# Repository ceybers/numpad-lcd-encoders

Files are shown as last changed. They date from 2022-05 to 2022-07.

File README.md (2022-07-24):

# numpad-lcd-encoders

## 📻 Project Description

A wired numberpad in 4×4 layout, with 3× rotary encoders, and a 128×64 LCD display.

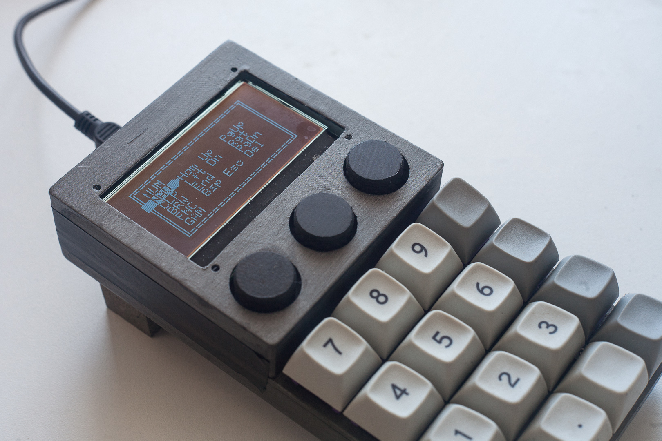
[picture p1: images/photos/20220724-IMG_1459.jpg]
Photo of first prototype


## 🧰 Features

- 4×4 programmable keys
- 3× rotary encoders (rotate and click)
- 128×64 3.25" LCD display
- [KMK firmware](https://github.com/KMKfw/kmk_firmware)
- Micro-USB connector 

## 📐 Changes

- Changed from 5×3 layout to 4×3 layout
- Changed screen to `12864-WB-33V`
- Changed from standoff plates to enclosed shell
- Increased switch plate thickness from 1.5mm to 3.0mm
- Removed holes in bottom plate for trimpot/reset button

## ⏳ Issues

> ⚠ Not suitable for actual use. Use at your own risk!

- Spacing for switches is tight, to the point that the plate will warp and might snap (printer tolerances may vary)
- Top shell around screen can't be secured to rest of case
- Shell too tall for even 20mm rotary encoders

See: [Lessons Learnt Part 1](lessons1.md), [Part 2](lessons2.md), and [Part 3](lessons3.md)

## 🛒 Bill of Materials (BoM)

> ⚠ Bill still hasn't been updated

| Item | Size | Qty | Store |
| ---- | ---- | --- | ----- |
| Raspberry Pi Pico | N/A | 1 | [Raspberry official](https://www.raspberrypi.com/products/raspberry-pi-pico/)
| EC11 Rotary Encoder | ø6×20mm shaft | 3 | [Robotics.org.za](https://www.robotics.org.za/EC11-VER-20)
| LCD Display 128×64 | 93×70mm OD | 1 | [Robotics.org.za](https://www.robotics.org.za/12864-WH-33V)
| ~~LCD I2C Interface Module~~<sup>1</sup> | N/A | ~~1~~ | [Robotics.org.za](https://www.robotics.org.za/6970622931577)
| Switches | MX | 15 |
| Diodes, 1N4148 | N/A | 18 |
| Standoffs | M3×10mm | 6 | [Robotics.org.za](https://www.robotics.org.za/M3-NYLON-KIT)
| Standoffs | M3×8mm | 4 |
| Standoffs | M3×6mm | 4 |
| Screws | M3×6mm | 6 |
| Screws | M2×?mm | 4 |
| Nuts | M3 | 6 |
| Nuts | M2 | 4 |
| 3D printed shell | N/A | 3 pcs |
| Encoder knobs | ø18×16mm | 3 pcs |
| JST-SH male breakout (optional) | JST-SH 6 pin | 4 pcs | [Robotics.org.za](https://www.robotics.org.za/4772), [Pololu](https://www.pololu.com/product/4772)
| JST-SH female connectors (optional) | JST-SH 6 pin | 4 pcs | [Robotics.org.za](https://www.robotics.org.za/JST-XH-6P-KIT) |

Notes:
1. I2C interface not required for the ST7565 controller version of the LCD board as it already utilises SPI.

---

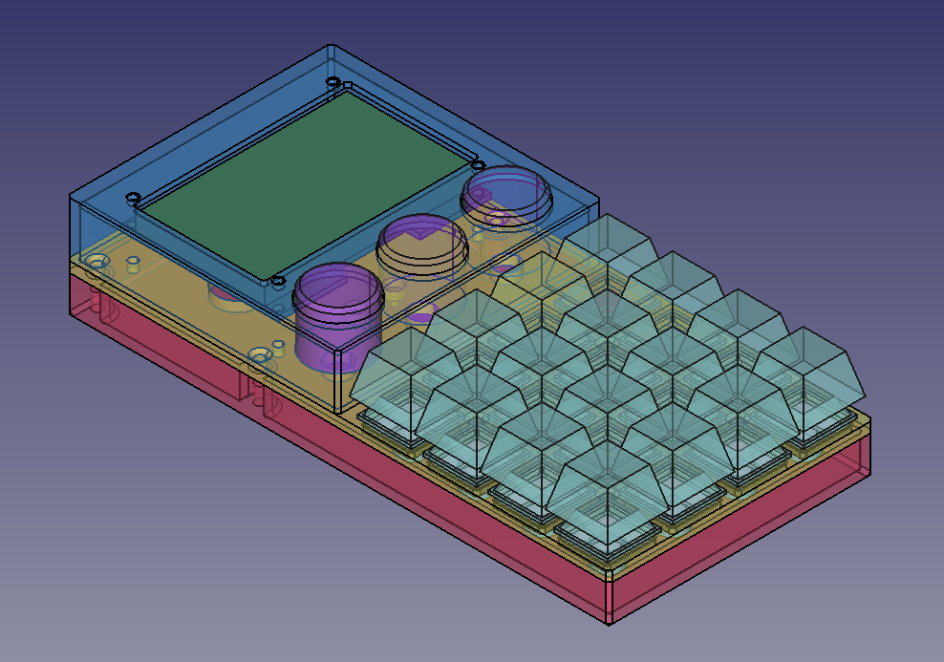
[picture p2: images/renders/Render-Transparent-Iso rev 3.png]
Render of the numberpad pad (transparent)

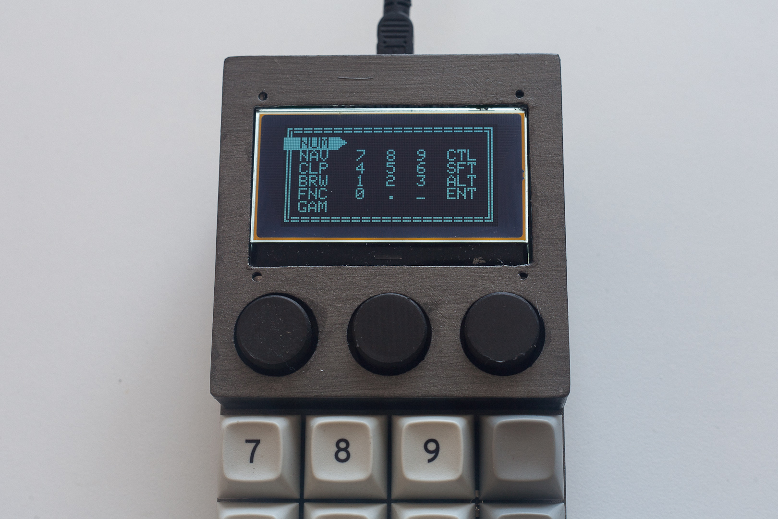
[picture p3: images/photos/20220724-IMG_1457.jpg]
Photo showing a close-up of the screen

## 🔗 References

- [KMK firmware](https://github.com/KMKfw/kmk_firmware)
- [Raspberry Pi Pico Datasheet](https://datasheets.raspberrypi.com/pico/pico-datasheet.pdf)
- [CircuitPython UF2 for Pico](https://circuitpython.org/board/raspberry_pi_pico/)

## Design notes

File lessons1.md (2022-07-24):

# Lessons Learnt Part 1

## Prototype 1
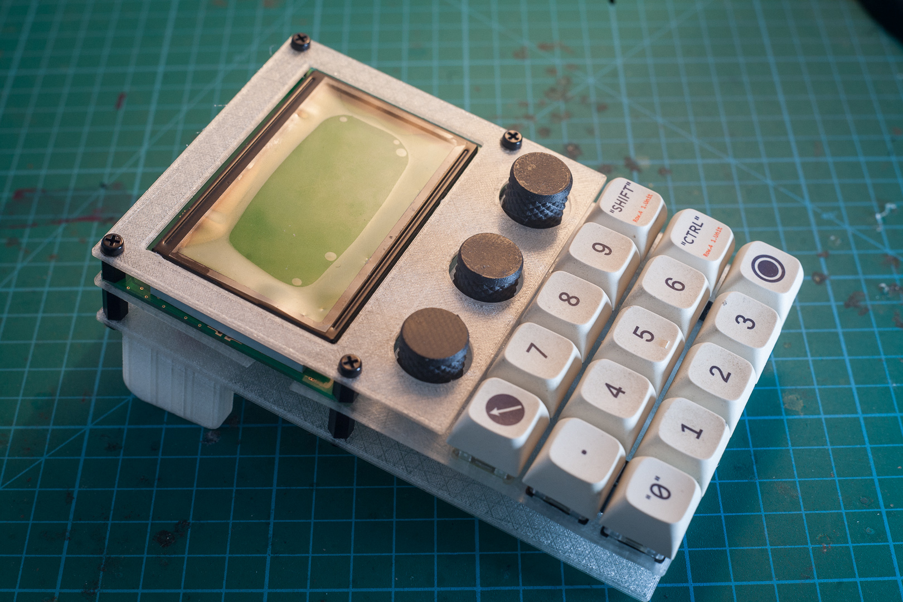
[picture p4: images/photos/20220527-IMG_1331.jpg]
High angle

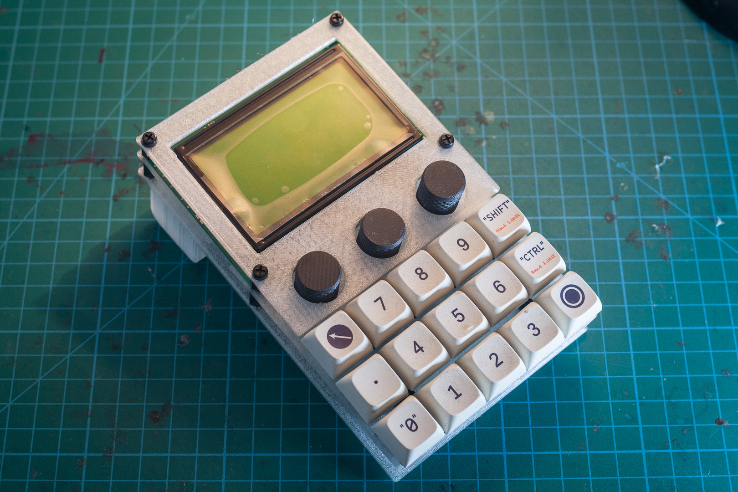
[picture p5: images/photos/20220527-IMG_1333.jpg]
Low angle

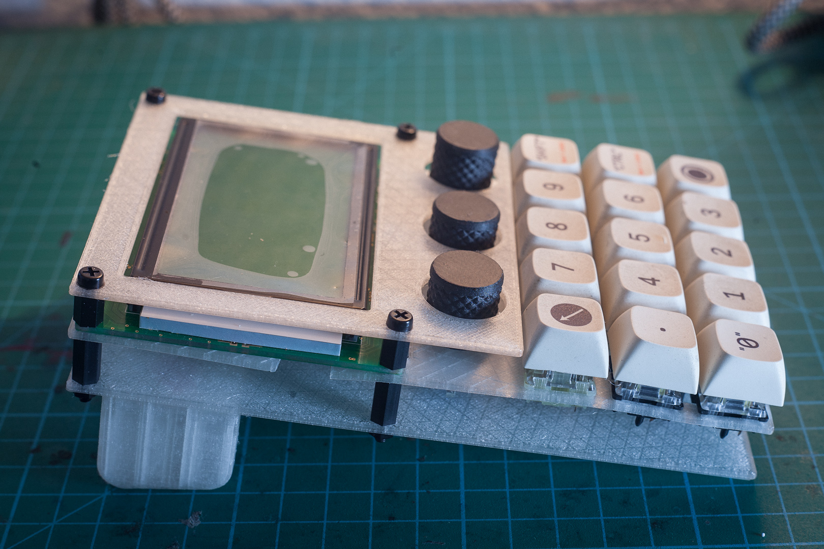
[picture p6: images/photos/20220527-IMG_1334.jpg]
Side view


## Closeups
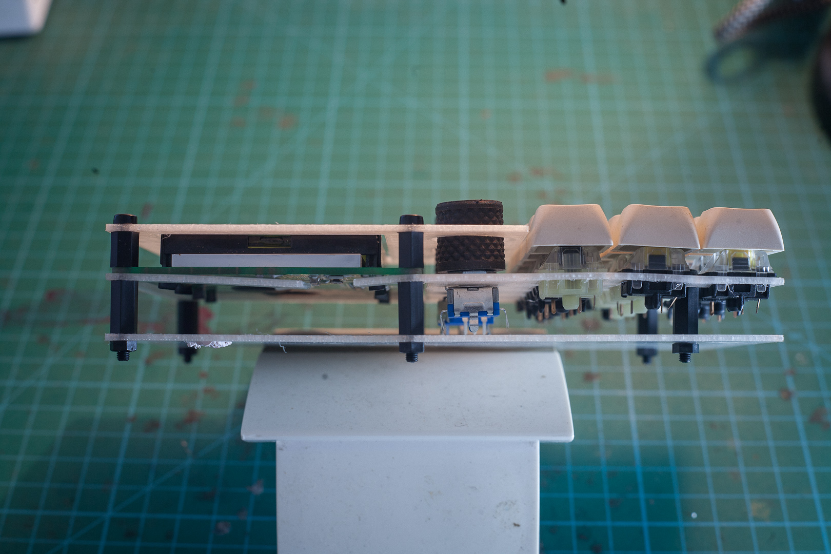
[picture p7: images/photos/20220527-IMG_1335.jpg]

LHS section view. Pictured with 8mm and 12mm standoffs

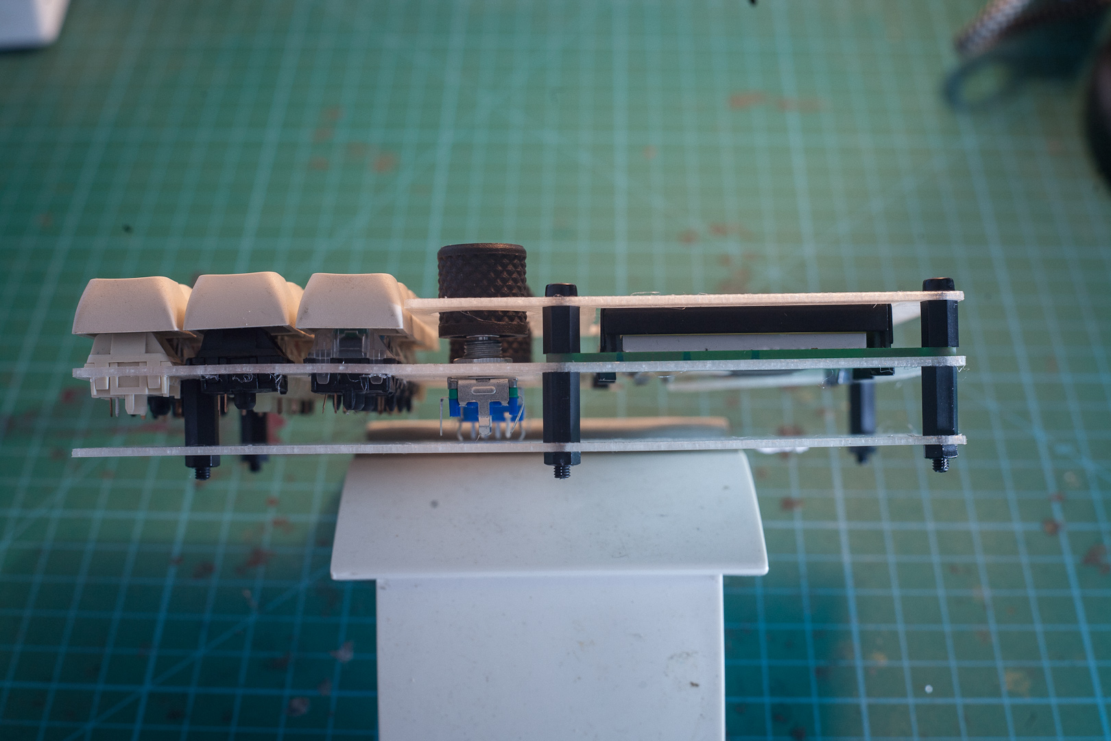
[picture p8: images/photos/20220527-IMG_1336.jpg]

RHS section view

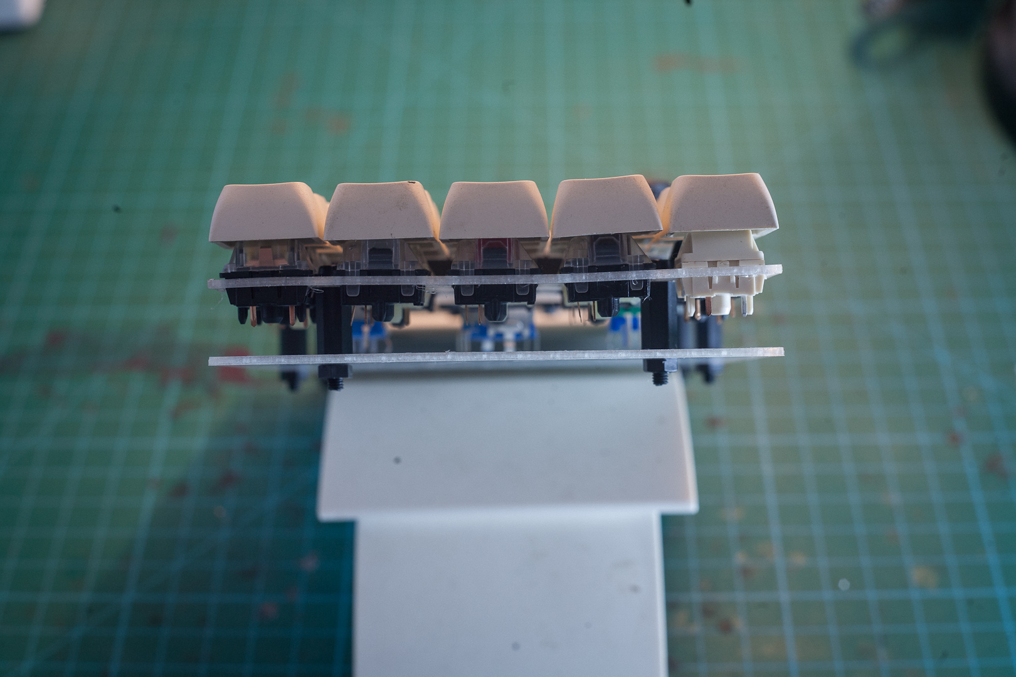
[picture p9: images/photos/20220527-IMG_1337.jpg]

Plate warping from bottom

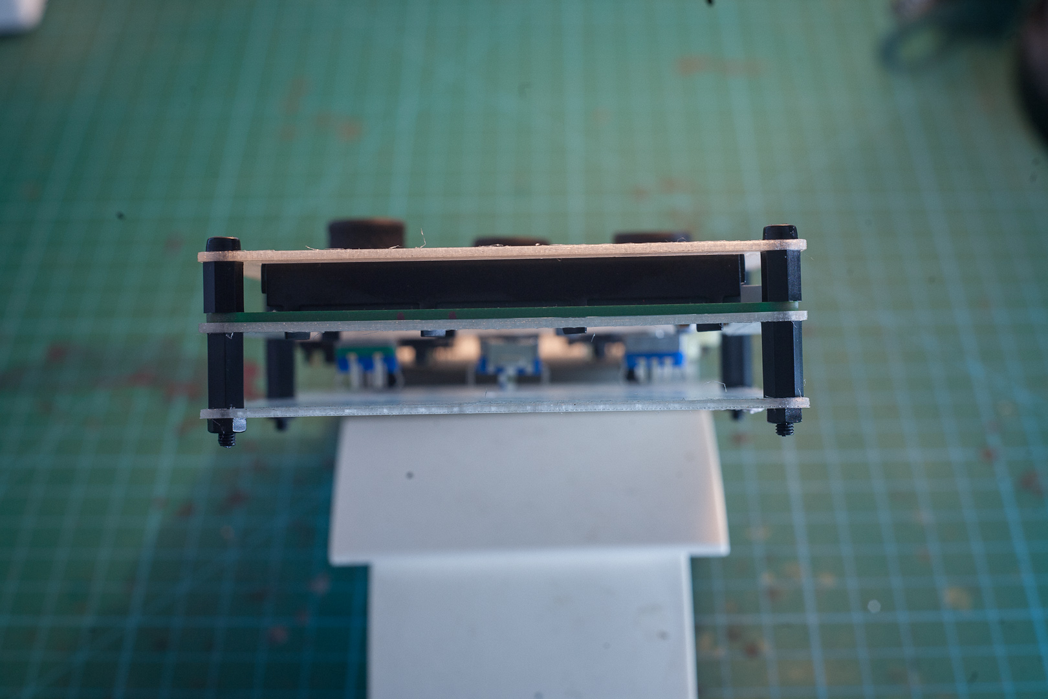
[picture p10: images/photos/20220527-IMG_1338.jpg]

VIew of plates from top - OK

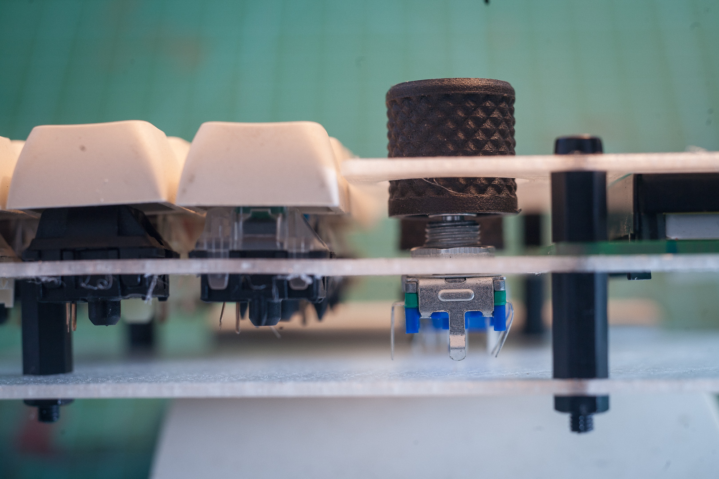
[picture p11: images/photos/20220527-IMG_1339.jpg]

Height of 16mm high knob on 20mm encoder versus plate

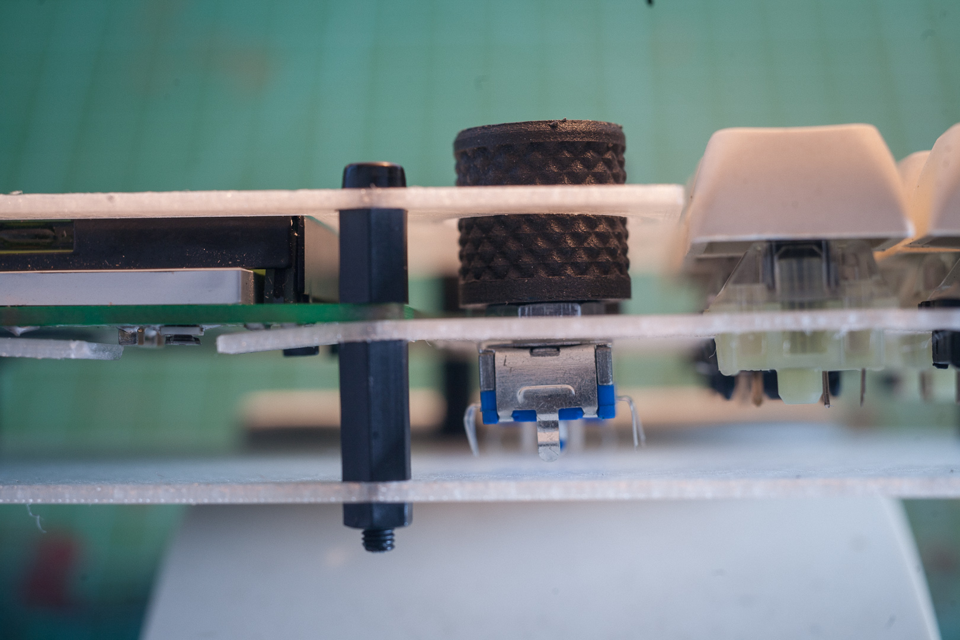
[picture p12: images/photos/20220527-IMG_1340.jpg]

Height of 16mm high knob on 15mm encoder versus plate

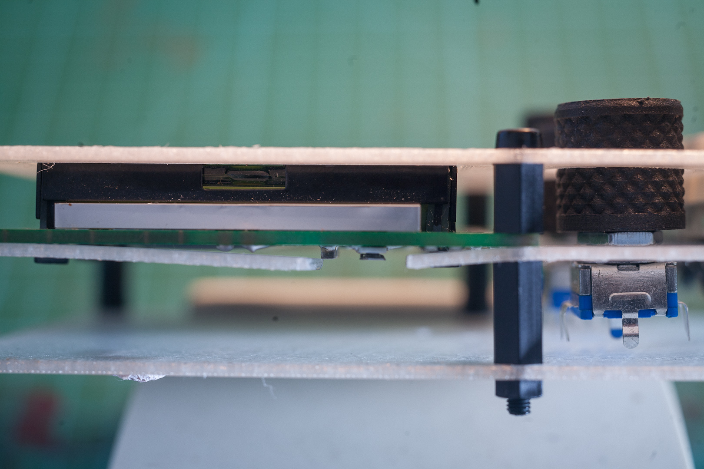
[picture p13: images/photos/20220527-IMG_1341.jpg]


Components below LCD PCB colliding with plate

# 🔗 Links:
 - [Lessons Learnt Part 2](lessons2.md)
 - [Lessons Learnt Part 3](lessons3.md)
 - [Readme](README.md)

---

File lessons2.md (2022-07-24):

# Lessons Learnt Part 2

## Prototype 1
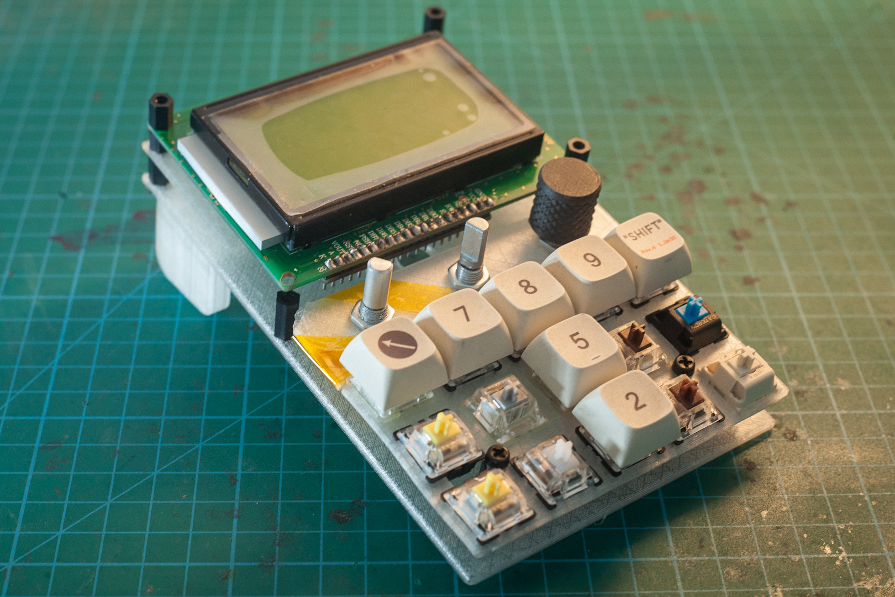
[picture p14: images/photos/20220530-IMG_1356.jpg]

Broke the plate while trying to remove the knobs off the 15mm encoders in order to replace with 20mm encoders. The 3D printed knobs a
were extremely tight fits.

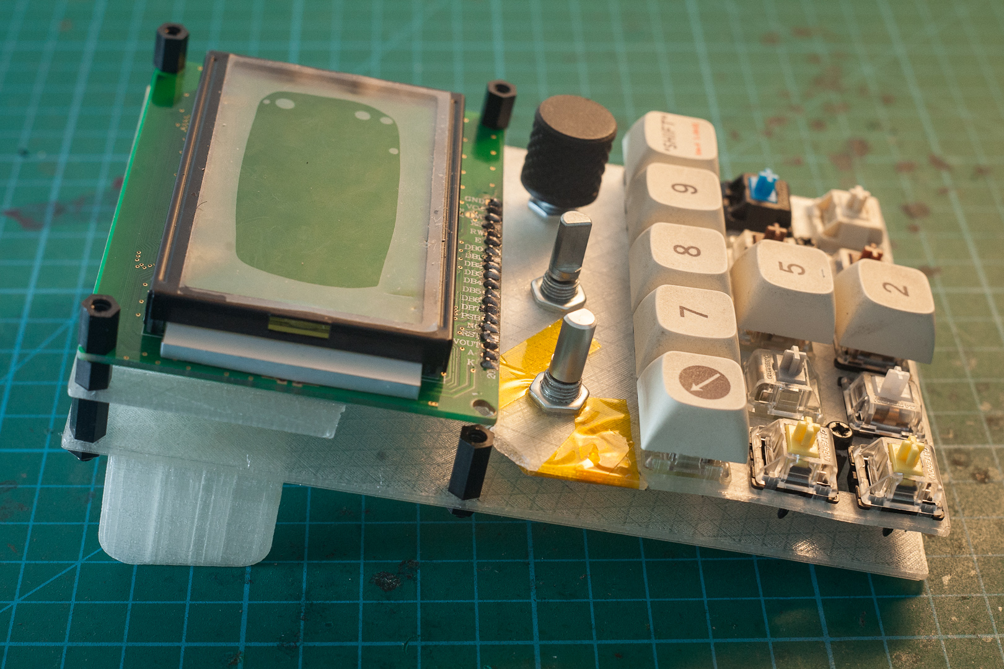
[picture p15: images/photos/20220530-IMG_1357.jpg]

Please excuse the poor soldering - changing over to lead-free solder is proving a challenge. Note: This I2C interface board is not required when using ST7920 LCD displays.

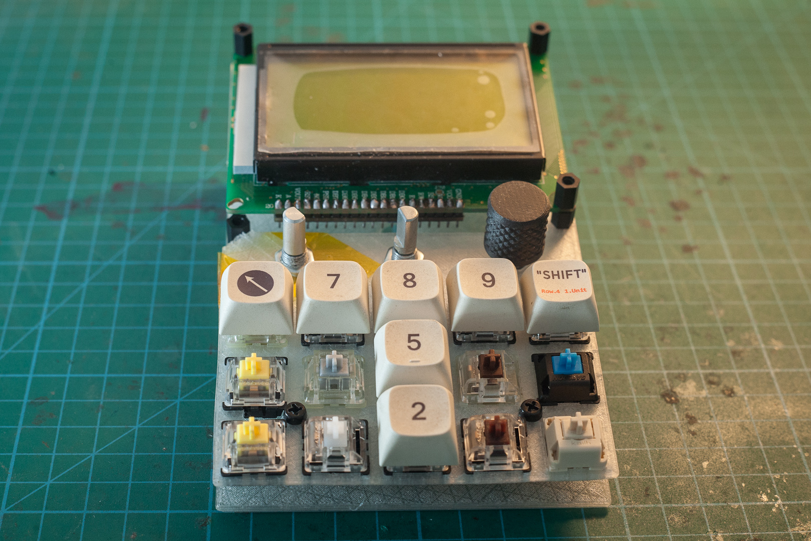
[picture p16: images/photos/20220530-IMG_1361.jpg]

Note the size of the screw heads versus the bottom flange on the switches.

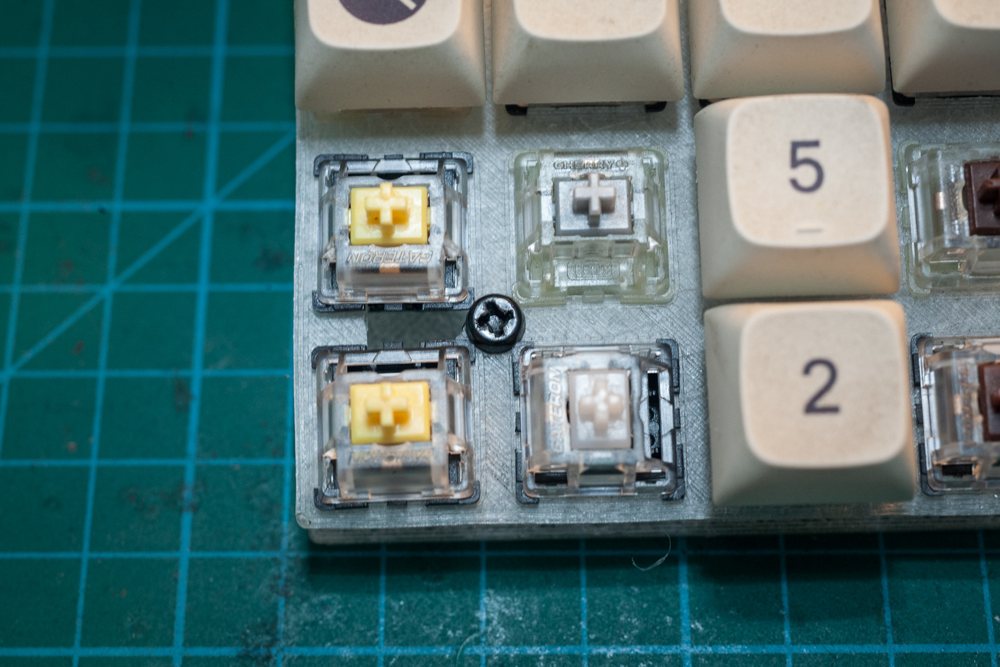
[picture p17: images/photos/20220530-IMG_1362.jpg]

Close up. These are M3 nylon screws.

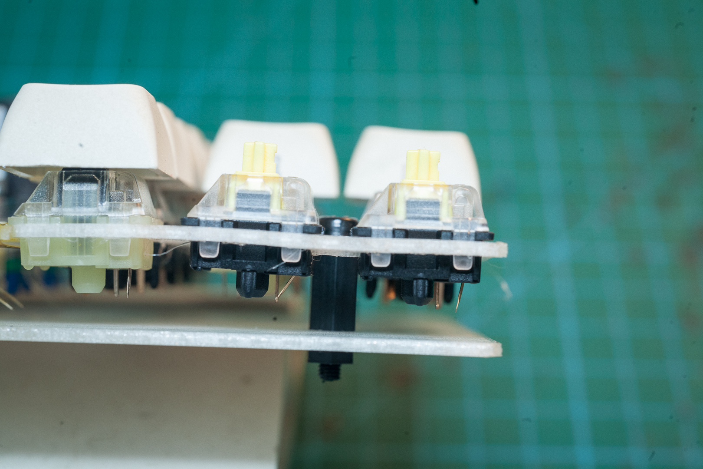
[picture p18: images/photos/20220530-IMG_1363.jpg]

Section view. About twice the height.

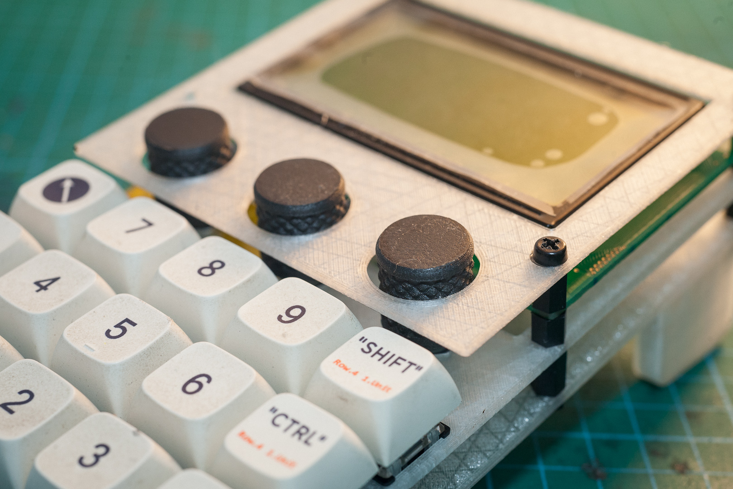
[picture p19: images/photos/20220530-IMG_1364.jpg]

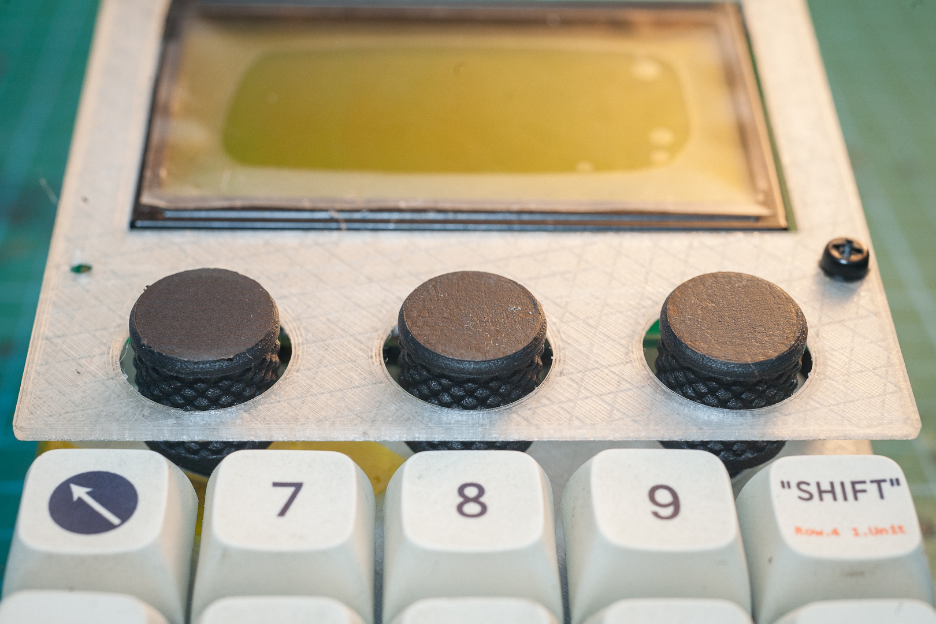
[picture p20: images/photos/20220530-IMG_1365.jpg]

Close up of the dials on 20mm encoders. This is using 6mm + 8mm standoffs on the top plate.

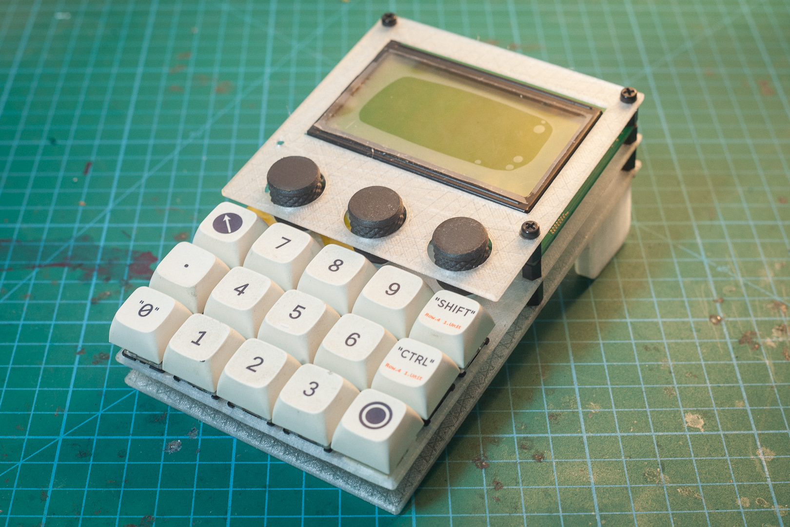
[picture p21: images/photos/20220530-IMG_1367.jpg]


# 🔗 Links:
 - [Lessons Learnt Part 1](lessons1.md)
 - [Lessons Learnt Part 3](lessons3.md)
 - [Readme](README.md)

---

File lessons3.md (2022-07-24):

# Lessons Learnt Part 3

## Prototype 2
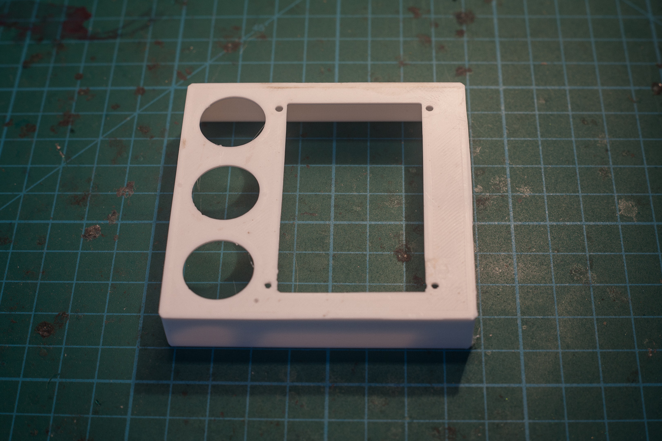
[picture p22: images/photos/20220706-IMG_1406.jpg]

Top shell. Initial plan was to secure it with screws and standoffs to the LCD but the dimensions didn't work out.

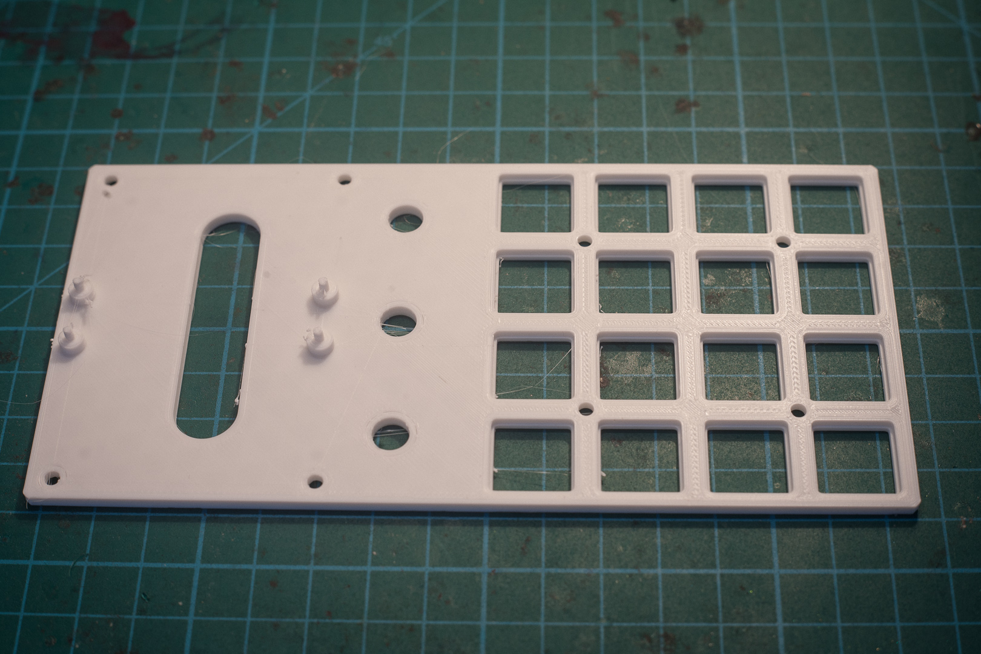
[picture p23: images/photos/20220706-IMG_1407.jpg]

Middle plate. Worked well, except for the pins to hold the MCU in place. These break off incredibly easily.

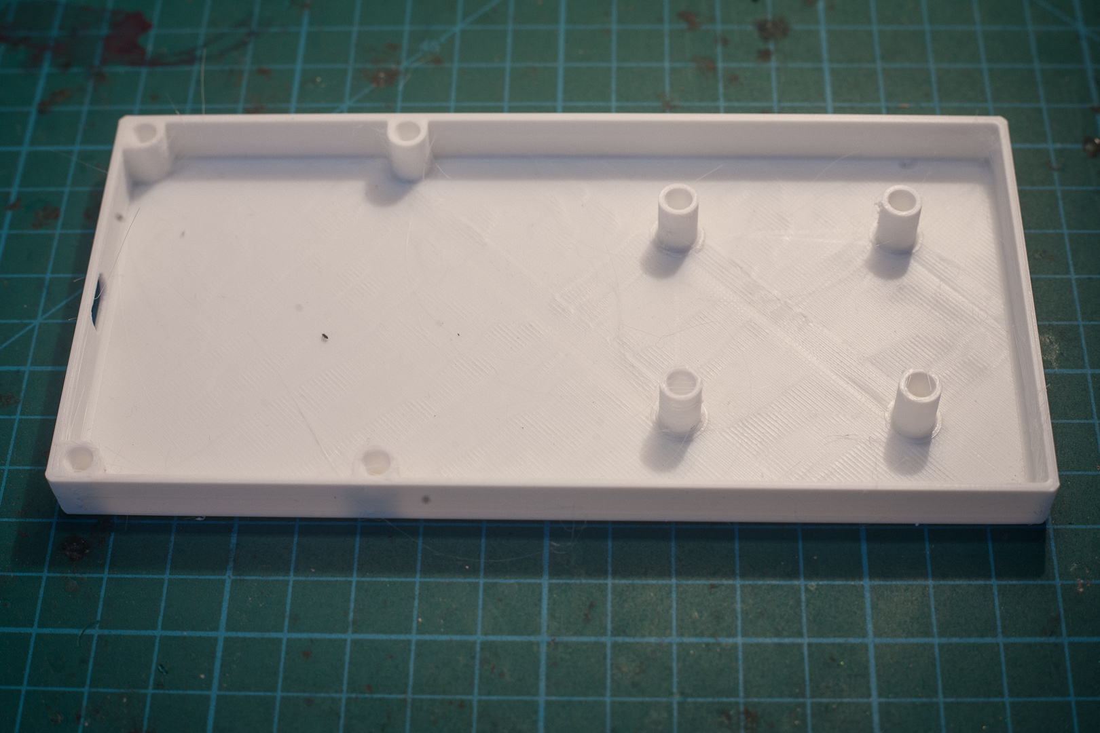
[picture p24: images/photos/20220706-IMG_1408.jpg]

Bottom shell. Pilot fillet for the heat set inserts worked well. Though for the next build I'd rather place the walls on the middle insert, and have the bottom plate just be a flat plate with holes for screws.

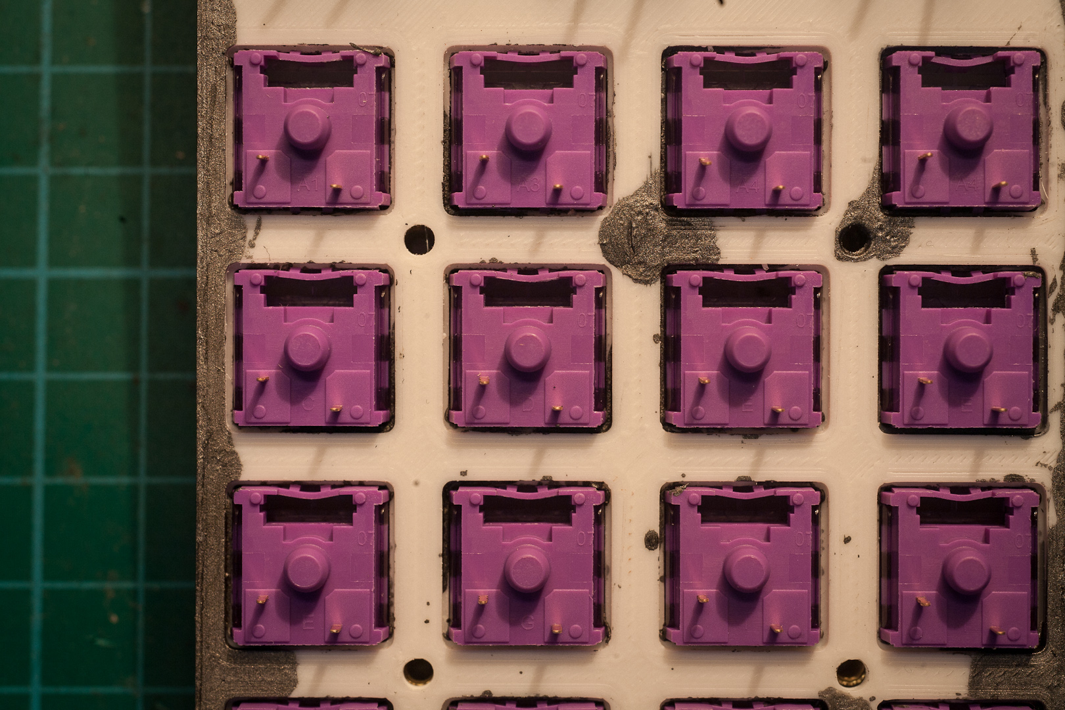
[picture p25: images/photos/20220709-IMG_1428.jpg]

Dimensions/tolerances for the cutouts for the switches were slightly off, you can see they're a bit too tight.

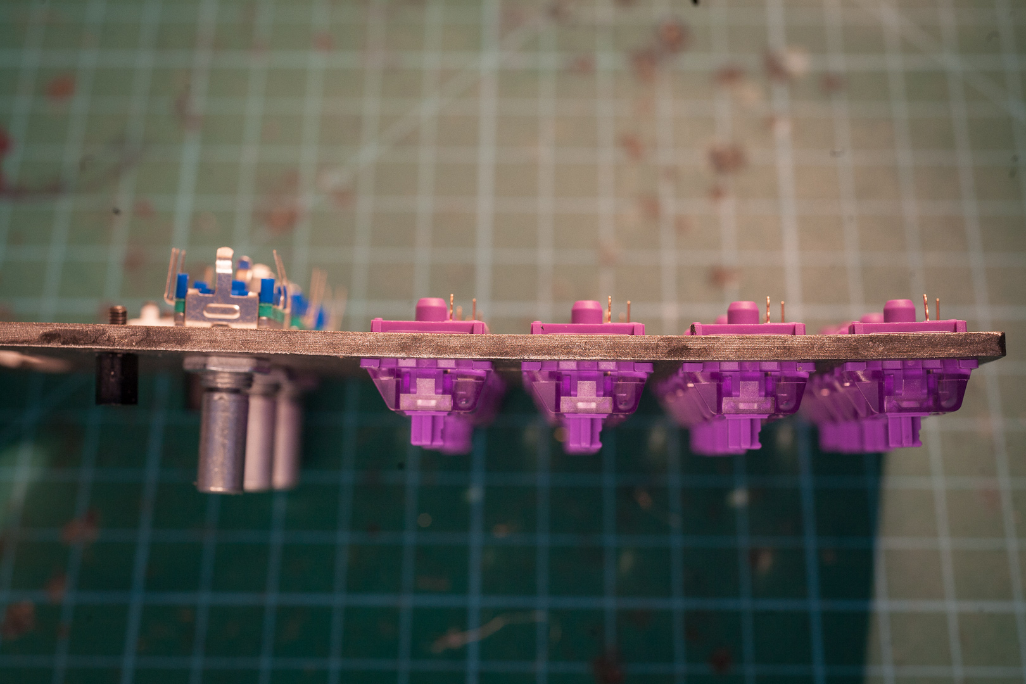
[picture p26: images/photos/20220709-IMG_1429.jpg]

Plate warps slightly with all the switches installed, but not as badly as before.

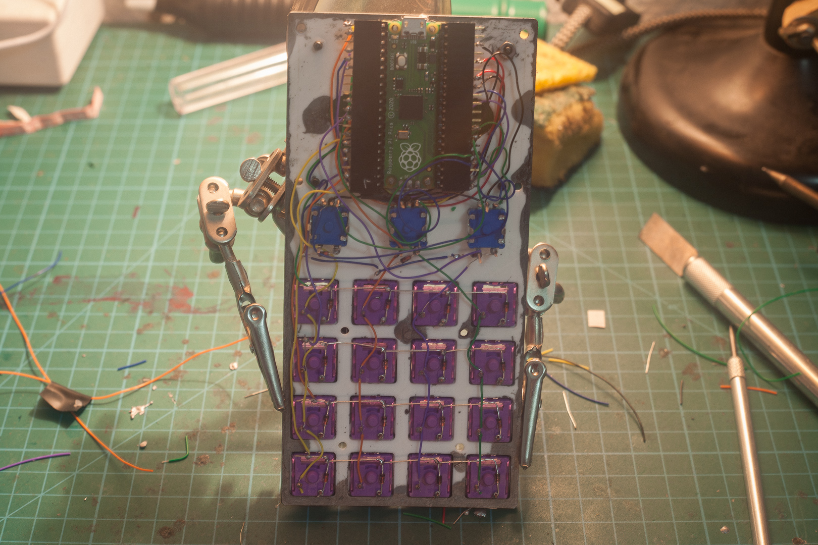
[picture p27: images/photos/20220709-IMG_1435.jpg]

Connected the components to the MCU with 90 degree SIL headers on the Pico, and soldering 30 AWG wire to female headers. Once everything is tested, the pins and joints are covered in insulation tape to prevent the wires moving and shorting neighbouring pins.


Screws fit snugly between the switches.


Cutouts around the rotary encoders are slightly off-center.


Window around the screen can be reduced to only the printable area of the LCD.


Top shell being held in place with insulation tape.

# 🔗 Links:
 - [Lessons Learnt Part 1](lessons1.md)
 - [Lessons Learnt Part 2](lessons2.md)
 - [Readme](README.md)

---

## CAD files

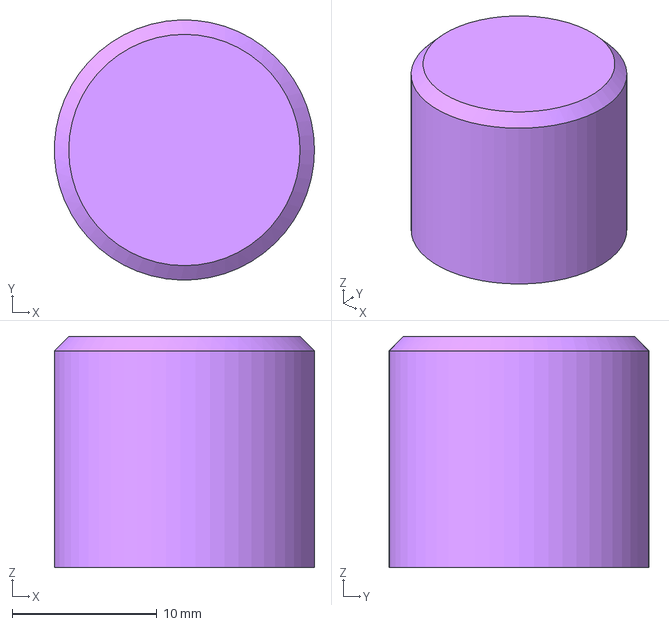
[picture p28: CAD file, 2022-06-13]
freecad/Dial_18x16mm.FCStd
18.0 x 18.0 x 16.0 mm

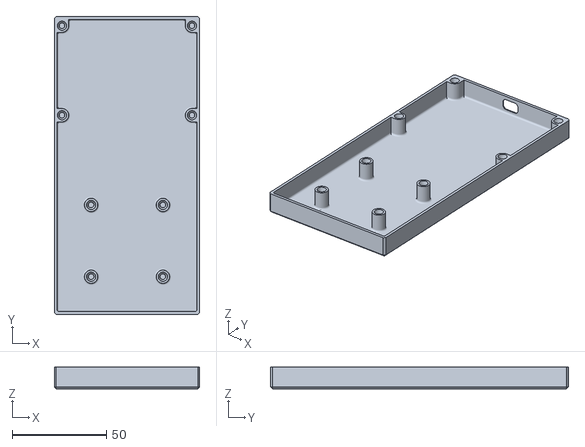
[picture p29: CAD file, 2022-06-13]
stl/Case4x4-BottomShell.stl
77.2 x 158.2 x 11.5

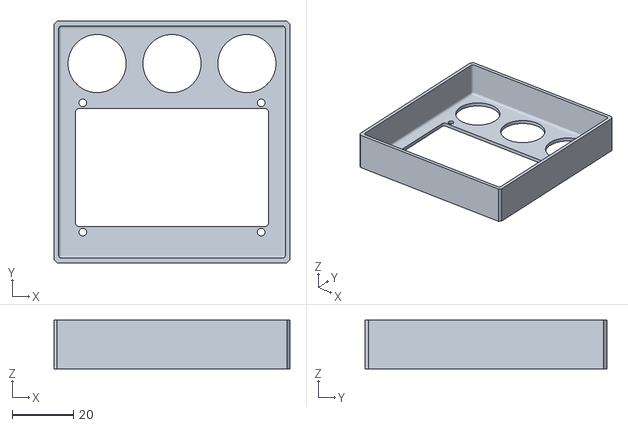
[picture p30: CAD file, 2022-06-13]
stl/Case4x4-TopShell.stl
77.2 x 79.0 x 16.0

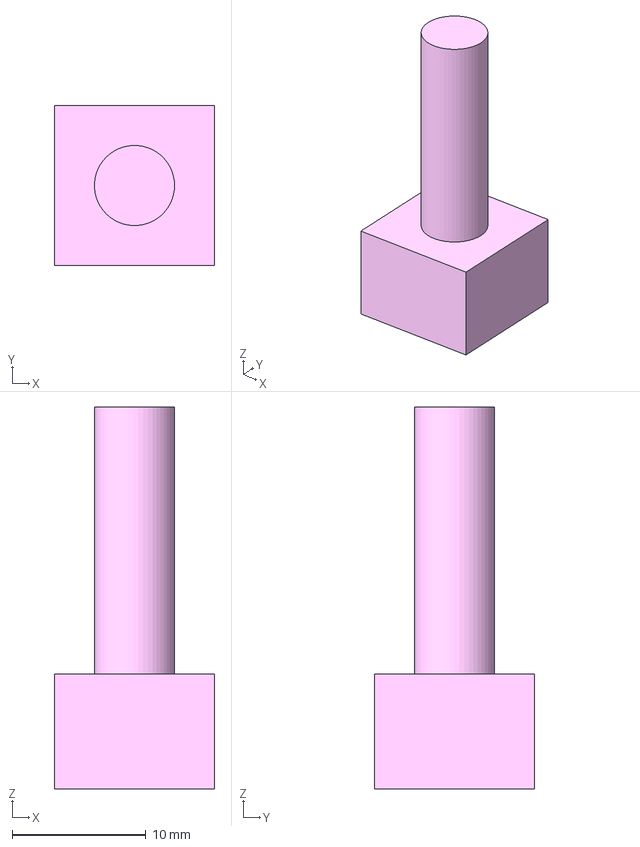
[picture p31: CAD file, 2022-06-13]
freecad/EC11.FCStd
12.0 x 12.0 x 28.6 mm

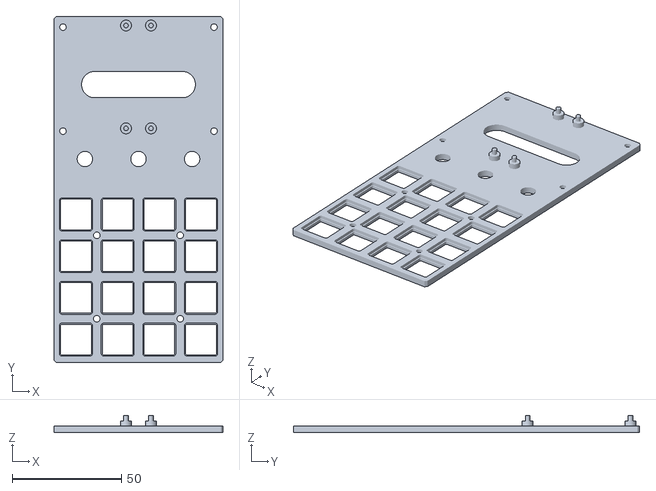
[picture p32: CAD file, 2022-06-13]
stl/Case4x4-MiddlePlate.stl
77.2 x 158.2 x 7.98

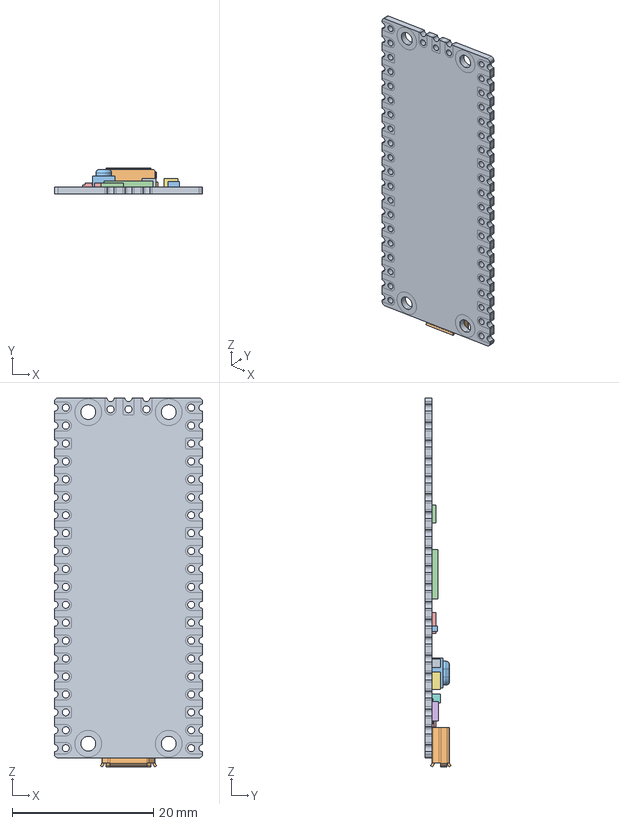
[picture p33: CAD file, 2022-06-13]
freecad/Pico-R3.FCStd
21.0 x 3.73 x 52.3 mm
PICO_REF_BOARD.STEP
PICO_REF_USB.STEP
PICO_REF_SWITCH.STEP
PICO_REF_MICROCONTROLLER.STEP
PICO_REF_LED.STEP
PICO_REF_ONSEMI.STEP
PICO_BOURNS.STEP
PICO_MURATA.STEP
PICO_MURATA.STEP001
PICO_RICHTEK.STEP
PICO_DIODES.STEP
PICO_AEL.STEP
PICO_WINBOND.STEP

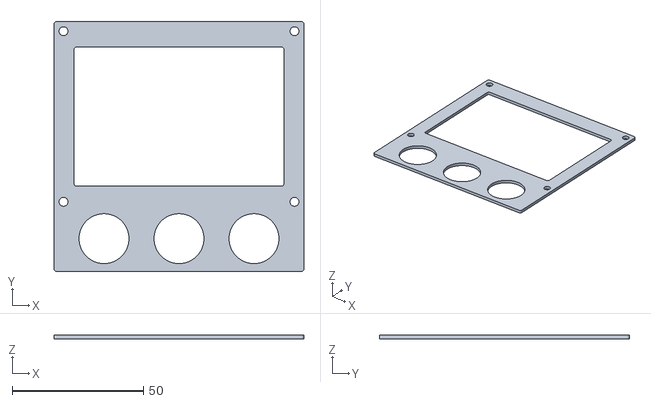
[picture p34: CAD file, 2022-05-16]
stl/Numpad-LCD-Encoder-Top-Plate.stl
95.2 x 95.2 x 1.50

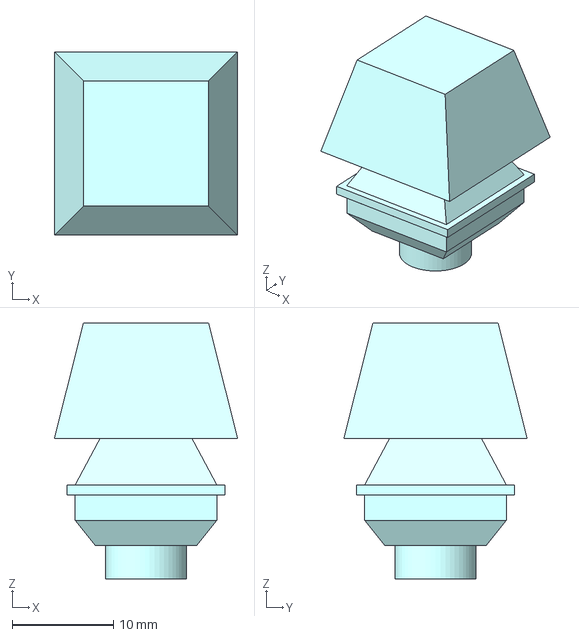
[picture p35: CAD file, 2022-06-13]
freecad/MX_Switch_1u.FCStd
18.1 x 18.1 x 25.3 mm

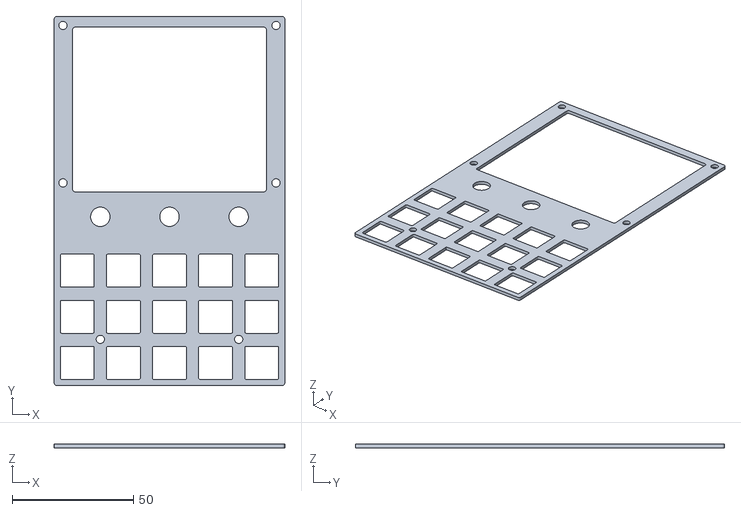
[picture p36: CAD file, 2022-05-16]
stl/Numpad-LCD-Encoder-Middle-Plate.stl
95.2 x 152.4 x 1.50

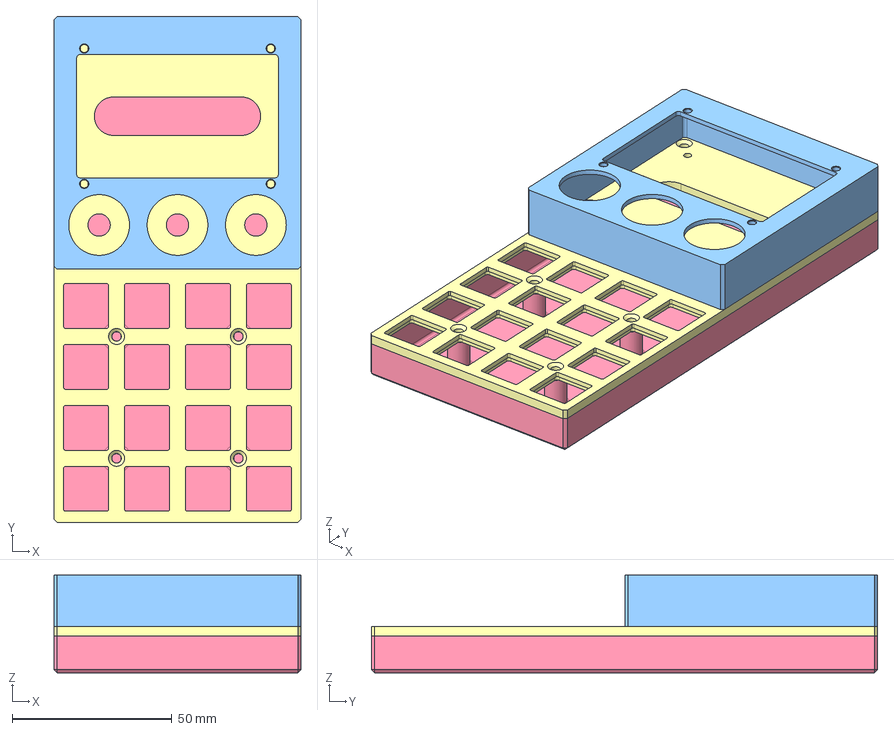
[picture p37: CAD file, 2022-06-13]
freecad/Case4x4.FCStd
77.2 x 158.2 x 30.5 mm
TopShellNice
MiddlePlateNice
BottomShellNice

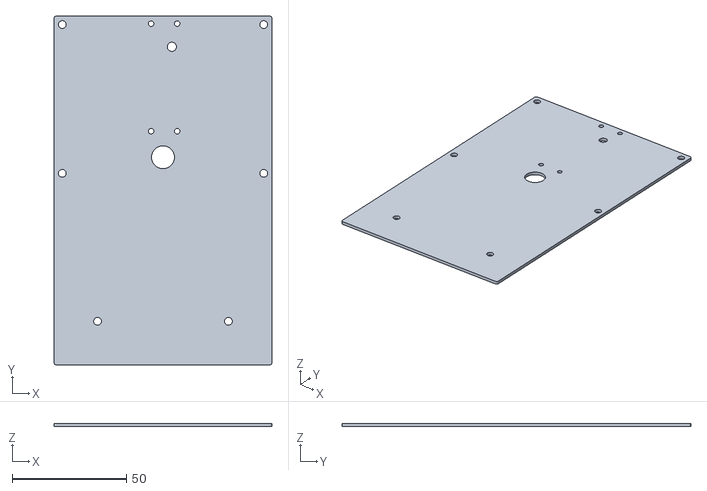
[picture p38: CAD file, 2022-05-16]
stl/Numpad-LCD-Encoder-Bottom-Plate.stl
95.2 x 152.4 x 1.50

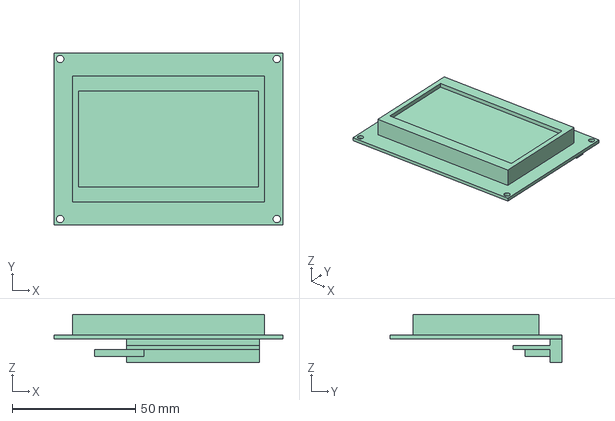
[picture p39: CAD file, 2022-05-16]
freecad/LCD_12864.FCStd
93.0 x 70.0 x 19.5 mm

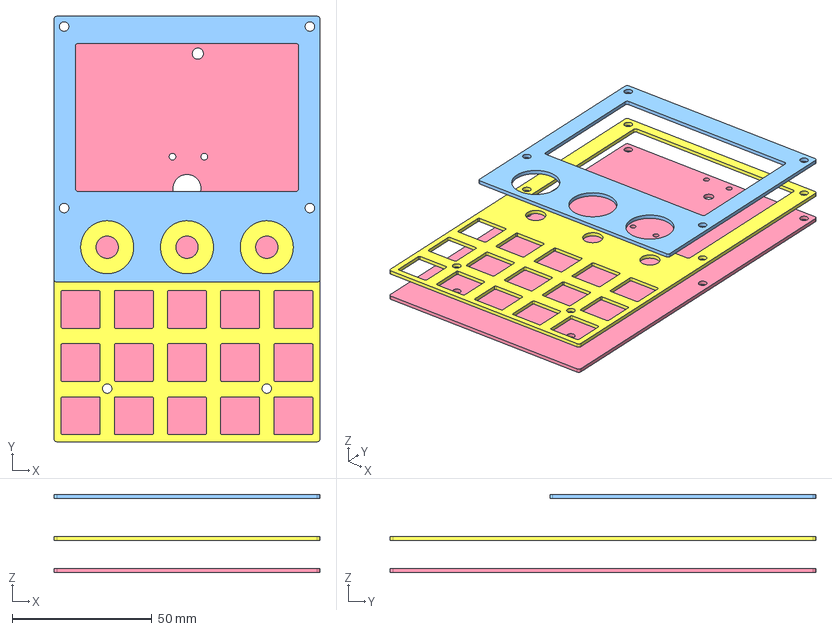
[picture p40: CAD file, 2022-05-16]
freecad/Numpad-LCD-Encoder.FCStd
95.2 x 152.4 x 28.0 mm
Middle_Plate
Bottom_Plate
Top_Plate

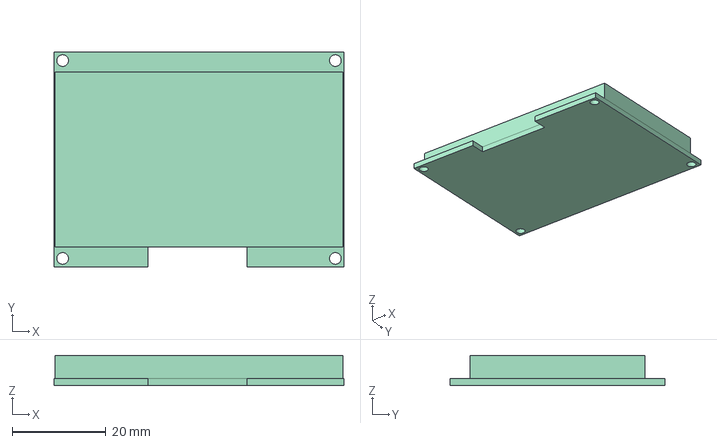
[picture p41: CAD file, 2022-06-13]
freecad/12864-WB-33V.FCStd
62.0 x 46.0 x 6.50 mm

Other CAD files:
freecad/archive/MX_Switch_1u.FCStd
freecad/archive/Pico-R3.FCStd
freecad/archive/Dial_18x16mm.FCStd
freecad/archive/EC11.FCStd

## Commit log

2022-05-30 First prototype
2022-06-13 Rev 3 CAD phase
    [12864-WB-33V.FCStd, Case4x4-BottomShell.stl, Case4x4-MiddlePlate.stl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]
2022-07-24 Prototype 2 build
